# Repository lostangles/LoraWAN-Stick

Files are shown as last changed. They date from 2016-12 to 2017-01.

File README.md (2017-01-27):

# LoraWAN-Stick
PCB combining Atmega32u4, MTK3339 GPS module, and RN2903 LoraWAN module.

PCB



# Functionality
I wanted to make a single PCB that had some GPIO, communication interfaces, a module to transmit LoraWAN packets, and a way to get current location.  The LoraWAN stack is offloaded from the 32u4 and rests in a PIC microcontroller inside the RN2903.  This allows a simple interface of simply passing the payload from the 32u4 to the RN2903 without having to worry about the LoraWAN stack inside your project.

The LoraWAN-Stick incorporates the LiPo charging circuitry common to the Adafruit Feather line of dev boards, as well as follows the same pinout for attachment of Adafruit Featherwings.  Because both the RN2903 and GPS module use serial communications, serial communications with other nodes may be difficult; the GPS module uses the hardware UART, and communication to the RN2903 uses software serial.  From my experience, having multiple software serial interfaces tends to work in unexpected ways, and should probably be avoided without thorough testing.

# Pins
Pinout follows Adafruit Feather format as I wanted to be able to add compatability of Adafruit Featherwings to this project.
The 32u4 only has a single hardware UART, hard wired to the TX/RX of the GPS module.  These pins are broken out on the header.

The RN2903 is controlled by serial, but because the 32u4 has only a single UART, a software serial interface must be used.  The RN2903 is hardwired with its RX on pin 5 and TX on pin 10.  Reset for the RN2903 is hard wired to pin 6 and should be pulled high when not in reset state.  The RN2903 Pickit3 programming header is also broken out to update the firmware on the RN2903 directly.

#uC Info
The 32u4-AU microcontroller that I used here comes preconfigured to use the internal oscillator, thus the C7, C8, and XTAL pads can be left empty.  When configuring the microcontroller for the first time, it will not show up as a USB device until the bootloader has been flashed to it via ISP.  Once the bootloader has been flashed, it should show up as an Adafruit Feather 32u4 under Device Manager, and can be programmed/configured in the same manner as any of the Adafruit 32u4 Feathers.

#Radio Interface
The RN2903 by default communicates on 56000 baud.  The SoftwareSerial library is more reliable at slower speeds; to set the baudrate in the RN2903, you must send a low signal on the TX line for at least two character lengths, followed by 0x55 at the new baudrate requested.  Using the Arduino libraries, this might look like:

```
digitalWrite(10, LOW);
delay(500);
digitalWrite(10, HIGH);
rn2903.begin(9600);
rn2903.write(0x55);
```

#Fuse Settings
The bootloader included configures the 32u4 in 8 MHz in the same configuration as the Adafruit 32u4 Feathers.
The uC can be configured to run with an internal oscillator or an external oscillator.  If you use the 32u4-AU variant, the built in oscillator can be used in lieu of an external oscillator.  The fuse settings to configure the uC as such would be something like:

`avrdude -c dragon_isp -p m32u4 -U lfuse:w:0xe2:m -U hfuse:w:0xd8:m -U efuse:w:0xfb:m -U flash:w:Caterina-Feather32u4.hex -v`

# Bill Of Materials
https://github.com/lostangles/LoraWAN-Stick/blob/master/LoraWAN-Stick.xlsx

Total cost: $52.52

U3	RN2903-I/RM095	RN2903-I_RM095:XCVR_RN2903-I%2fRM095	Microchip
U2	ATmega32U4-AU	Housings_QFP:TQFP-44_10x10mm_Pitch0.8mm	
U1	FGPMMOPA6H	FGPMMOPA6H:FGPMMOPA6H	
P1	USB_OTG	Connect:USB_Mini-B	
R1	22	Resistors_SMD:R_0603_HandSoldering	
R2	22	Resistors_SMD:R_0603_HandSoldering	
U4	SPX3819	adafruit:adafruit-SOT23-5L	
R3	100k	Resistors_SMD:R_0603_HandSoldering	
C1	10uF	Capacitors_SMD:C_0603_HandSoldering	
C2	10uF	Capacitors_SMD:C_0603_HandSoldering	
C3	1uF	Capacitors_SMD:C_0603_HandSoldering	
D1	DIODESCH	Diodes_SMD:D_0805	
CN1	JST_2PIN-SMT	adafruit:adafruit-JST-PH-2-SMT	
C4	1uF	Capacitors_SMD:C_0603_HandSoldering	
SW1	SPST	open-project:SW_PUSH_SMD	
U5	MCP73831	arthurc:SOT23-5	
D2	LED-BAT	Diodes_SMD:D_0805	
R4	1k	Resistors_SMD:R_0603_HandSoldering	
R5	10k	Resistors_SMD:R_0603_HandSoldering	
C5	10uF	Capacitors_SMD:C_0603_HandSoldering	
R6	100k	Resistors_SMD:R_0603_HandSoldering	
R7	100k	Resistors_SMD:R_0603_HandSoldering	
C6	10uF	Capacitors_SMD:C_0603_HandSoldering	
JP3	PINHD-1X12	adafruit:adafruit-1X12	
JP1	CONN_01X16	Pin_Headers:Pin_Header_Straight_1x16	
JP2	PINHD-1X6	adafruit:adafruit-1X06	
ANT1	CON-SMA	misc:CON-SMA-EDGE	
D3	LED-RED	Diodes_SMD:D_0805	
R8	1k	Resistors_SMD:R_0603_HandSoldering	
D4	LED-POW	Diodes_SMD:D_0805	
R9	1k	Resistors_SMD:R_0603_HandSoldering	

# TODO 

Add ICP header for 32u4

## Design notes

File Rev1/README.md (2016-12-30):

# LoraWAN-Stick
PCB combining Atmega32u4, MTK3339 GPS module, and RN2903 LoraWAN module
This is rev 0; changes will probably need to be made once I get PCBs in and test them

OSHPark permalink: 
https://oshpark.com/shared_projects/INShZUhB

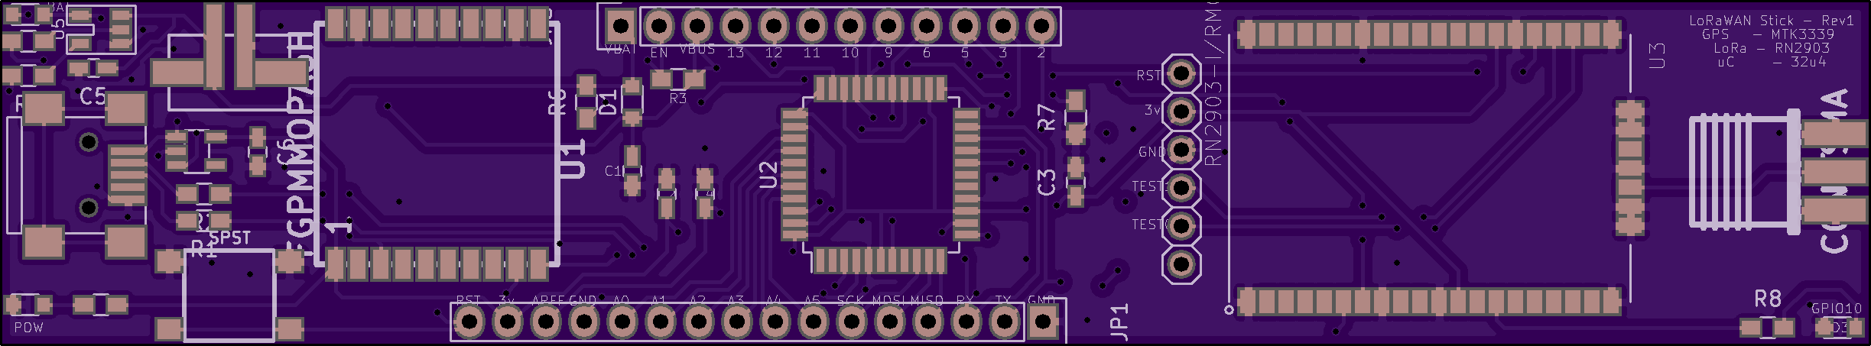
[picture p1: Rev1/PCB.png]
PCB


# Functionality
I wanted to make a single PCB that had some GPIO, communication interfaces, a module to transmit LoraWAN packets, and a way to get current location.  The LoraWAN stack is offloaded from the 32u4 and rests in a PIC microcontroller inside the RN2903.  This allows a simple interface of simply passing the payload from the 32u4 to the RN2903 without having to worry about the LoraWAN stack inside your project.

The LoraWAN-Stick incorporates the LiPo charging circuitry common to the Adafruit Feather line of dev boards, as well as follows the same pinout for attachment of Adafruit Featherwings.  Because both the RN2903 and GPS module use serial communications, serial communications with other nodes may be difficult; the GPS module uses the hardware UART, and communication to the RN2903 uses software serial.  From my experience, having multiple software serial interfaces tends to work in unexpected ways, and should probably be avoided without thorough testing.

# Pins
Pinout follows Adafruit Feather format as I wanted to be able to add compatability of Adafruit Featherwings to this project.
The 32u4 only has a single hardware UART, hard wired to the TX/RX of the GPS module.  These pins are broken out on the header.

The RN2903 is controlled by serial, but because the 32u4 has only a single UART, a software serial interface must be used.  The RN2903 is hardwired with its RX on pin 5 and TX on pin 10.  Reset for the RN2903 is hard wired to pin 6 and should be pulled high when not in reset state.  The RN2903 Pickit3 programming header is also broken out to update the firmware on the RN2903 directly.

# Bill Of Materials
https://github.com/lostangles/LoraWAN-Stick/blob/master/LoraWAN-Stick.xlsx

Total cost: $52.52

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

# TODO 

Verify all functionality

Verify pin header compatbility

Add ICP for 32u4

Verify software serial pins work correctly

Add mounting holes on corners

Add external oscillator

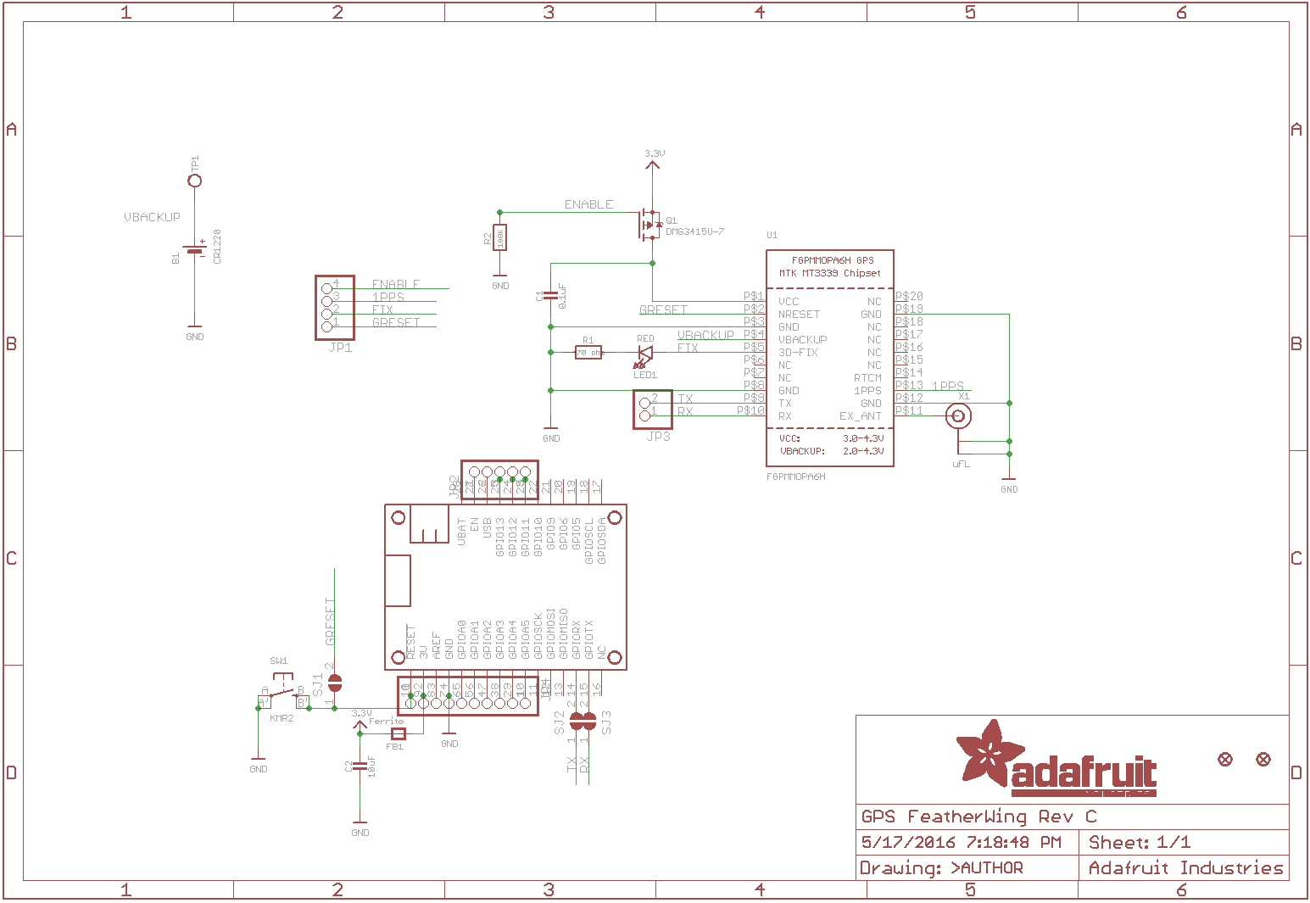
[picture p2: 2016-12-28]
Rev1/datasheets/gps_schem.png

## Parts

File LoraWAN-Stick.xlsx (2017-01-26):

Reference | Value | Footprint | Price | Link
U3 | RN2903-I/RM095 | RN2903-I_RM095:XCVR_RN2903-I%2fRM095 | 14.7 | http://www.digikey.com/products/en?mpart=RN2903-I%2FRM095&v=150
U2 | ATmega32U4-AU | Housings_QFP:TQFP-44_10x10mm_Pitch0.8mm | 6.32 | http://www.digikey.com/product-detail/en/atmel/ATMEGA32U4RC-AU/ATMEGA32U4RC-AU-ND/2507982
U1 | FGPMMOPA6H | FGPMMOPA6H:FGPMMOPA6H | 11.8 | https://www.aliexpress.com/item/FGPMMOPA6H-utilizes-the-MediaTek-new-generation-GPS-Chipset-MT3339/623742154.html
P1 | USB_OTG | Connect:USB_Mini-B | 0.6 | http://www.digikey.com/product-detail/en/edac-inc/690-005-299-043/151-1206-1-ND/4312192
R1 | 22 | Resistors_SMD:R_0603_HandSoldering | 0.1 | http://www.digikey.com/product-detail/en/yageo/RC0603JR-0722RL/311-22GRCT-ND/729690
R2 | 22 | Resistors_SMD:R_0603_HandSoldering | 0.1 | http://www.digikey.com/product-detail/en/yageo/RC0603JR-0722RL/311-22GRCT-ND/729690
U4 | SPX3819 | adafruit:adafruit-SOT23-5L | 0.72 | http://www.digikey.com/product-detail/en/exar-corporation/SPX3819M5-L-3-3-TR/1016-1873-1-ND/3586590
R3 | 100k | Resistors_SMD:R_0603_HandSoldering | 0.1 | http://www.digikey.com/product-detail/en/yageo/RC0603JR-07100KL/311-100KGRCT-ND/729645
C1 | 10uF | Capacitors_SMD:C_0603_HandSoldering | 0.15 | http://www.digikey.com/product-detail/en/murata-electronics-north-america/GRM188R60J106ME47D/490-3896-1-ND/965938
C2 | 10uF | Capacitors_SMD:C_0603_HandSoldering | 0.15 | http://www.digikey.com/product-detail/en/murata-electronics-north-america/GRM188R60J106ME47D/490-3896-1-ND/965938
C3 | 1uF | Capacitors_SMD:C_0603_HandSoldering | 0.1 | http://www.digikey.com/product-detail/en/murata-electronics-north-america/GRM188R61C105KA93D/490-1536-1-ND/587769
D1 | DIODESCH | Diodes_SMD:D_0805 | 0.47 | http://www.digikey.com/product-detail/en/on-semiconductor/MBR120VLSFT1G/MBR120VLSFT1GOSCT-ND/893874
CN1 | JST_2PIN-SMT | adafruit:adafruit-JST-PH-2-SMT | 0.55 | http://www.digikey.com/product-detail/en/jst-sales-america-inc/B2B-PH-SM4-TB(LF)(SN)/455-1734-1-ND/926831
C4 | 1uF | Capacitors_SMD:C_0603_HandSoldering | 0.1 | http://www.digikey.com/product-detail/en/murata-electronics-north-america/GRM188R61C105KA93D/490-1536-1-ND/587769
SW1 | SPST | open-project:SW_PUSH_SMD | 2.43 | http://www.digikey.com/product-detail/en/rafi-usa/1.14100.5030000/1715-1676-1-ND/583462
U5 | MCP73831 | arthurc:SOT23-5 | 0.58 | http://www.digikey.com/product-detail/en/microchip-technology/MCP73831T-2DCI-OT/MCP73831T-2DCI-OTCT-ND/1979804
D2 | LED-BAT | Diodes_SMD:D_0805 | 0.26 | http://www.digikey.com/product-detail/en/osram-opto-semiconductors-inc/LH-R974-LP-1/475-1415-1-ND/1802604
R4 | 1k | Resistors_SMD:R_0603_HandSoldering | 0.1 | http://www.digikey.com/product-detail/en/yageo/RC0603JR-071KL/311-1.0KGRCT-ND/729624
R5 | 10k | Resistors_SMD:R_0603_HandSoldering | 0.1 | http://www.digikey.com/product-detail/en/yageo/RC0603JR-0710KL/311-10KGRCT-ND/729647
C5 | 10uF | Capacitors_SMD:C_0603_HandSoldering | 0.15 | http://www.digikey.com/product-detail/en/murata-electronics-north-america/GRM188R60J106ME47D/490-3896-1-ND/965938
R6 | 100k | Resistors_SMD:R_0603_HandSoldering | 0.1 | http://www.digikey.com/product-detail/en/yageo/RC0603JR-07100KL/311-100KGRCT-ND/729645
R7 | 100k | Resistors_SMD:R_0603_HandSoldering | 0.1 | http://www.digikey.com/product-detail/en/yageo/RC0603JR-07100KL/311-100KGRCT-ND/729645
C6 | 10uF | Capacitors_SMD:C_0603_HandSoldering | 0.15 | http://www.digikey.com/product-detail/en/murata-electronics-north-america/GRM188R60J106ME47D/490-3896-1-ND/965938
JP3 | PINHD-1X12 | adafruit:adafruit-1X12 | 0.73 | http://www.digikey.com/product-detail/en/3m/951112-8622-AR/3M9330-ND/1959058
JP1 | CONN_01X16 | Pin_Headers:Pin_Header_Straight_1x16 | 0.76 | http://www.digikey.com/product-detail/en/amphenol-fci/68002-116HLF/609-3295-ND/1878570
JP2 | PINHD-1X6 | adafruit:adafruit-1X06
ANT1 | CON-SMA | misc:CON-SMA-EDGE | 2.98 | http://www.digikey.com/product-detail/en/taoglas-limited/EMPCB.SMAFSTJ.C.HT/931-1174-ND/3522338
D3 | LED-RED | Diodes_SMD:D_0805 | 0.26
R8 | 1k | Resistors_SMD:R_0603_HandSoldering | 0.1 | http://www.digikey.com/product-detail/en/yageo/RC0603JR-071KL/311-1.0KGRCT-ND/729624
D4 | LED-POW | Diodes_SMD:D_0805 | 0.26
R9 | 1k | Resistors_SMD:R_0603_HandSoldering | 0.1 | http://www.digikey.com/product-detail/en/yageo/RC0603JR-071KL/311-1.0KGRCT-ND/729624
PCB |  |  | 7.4
 |  |  | 52.52

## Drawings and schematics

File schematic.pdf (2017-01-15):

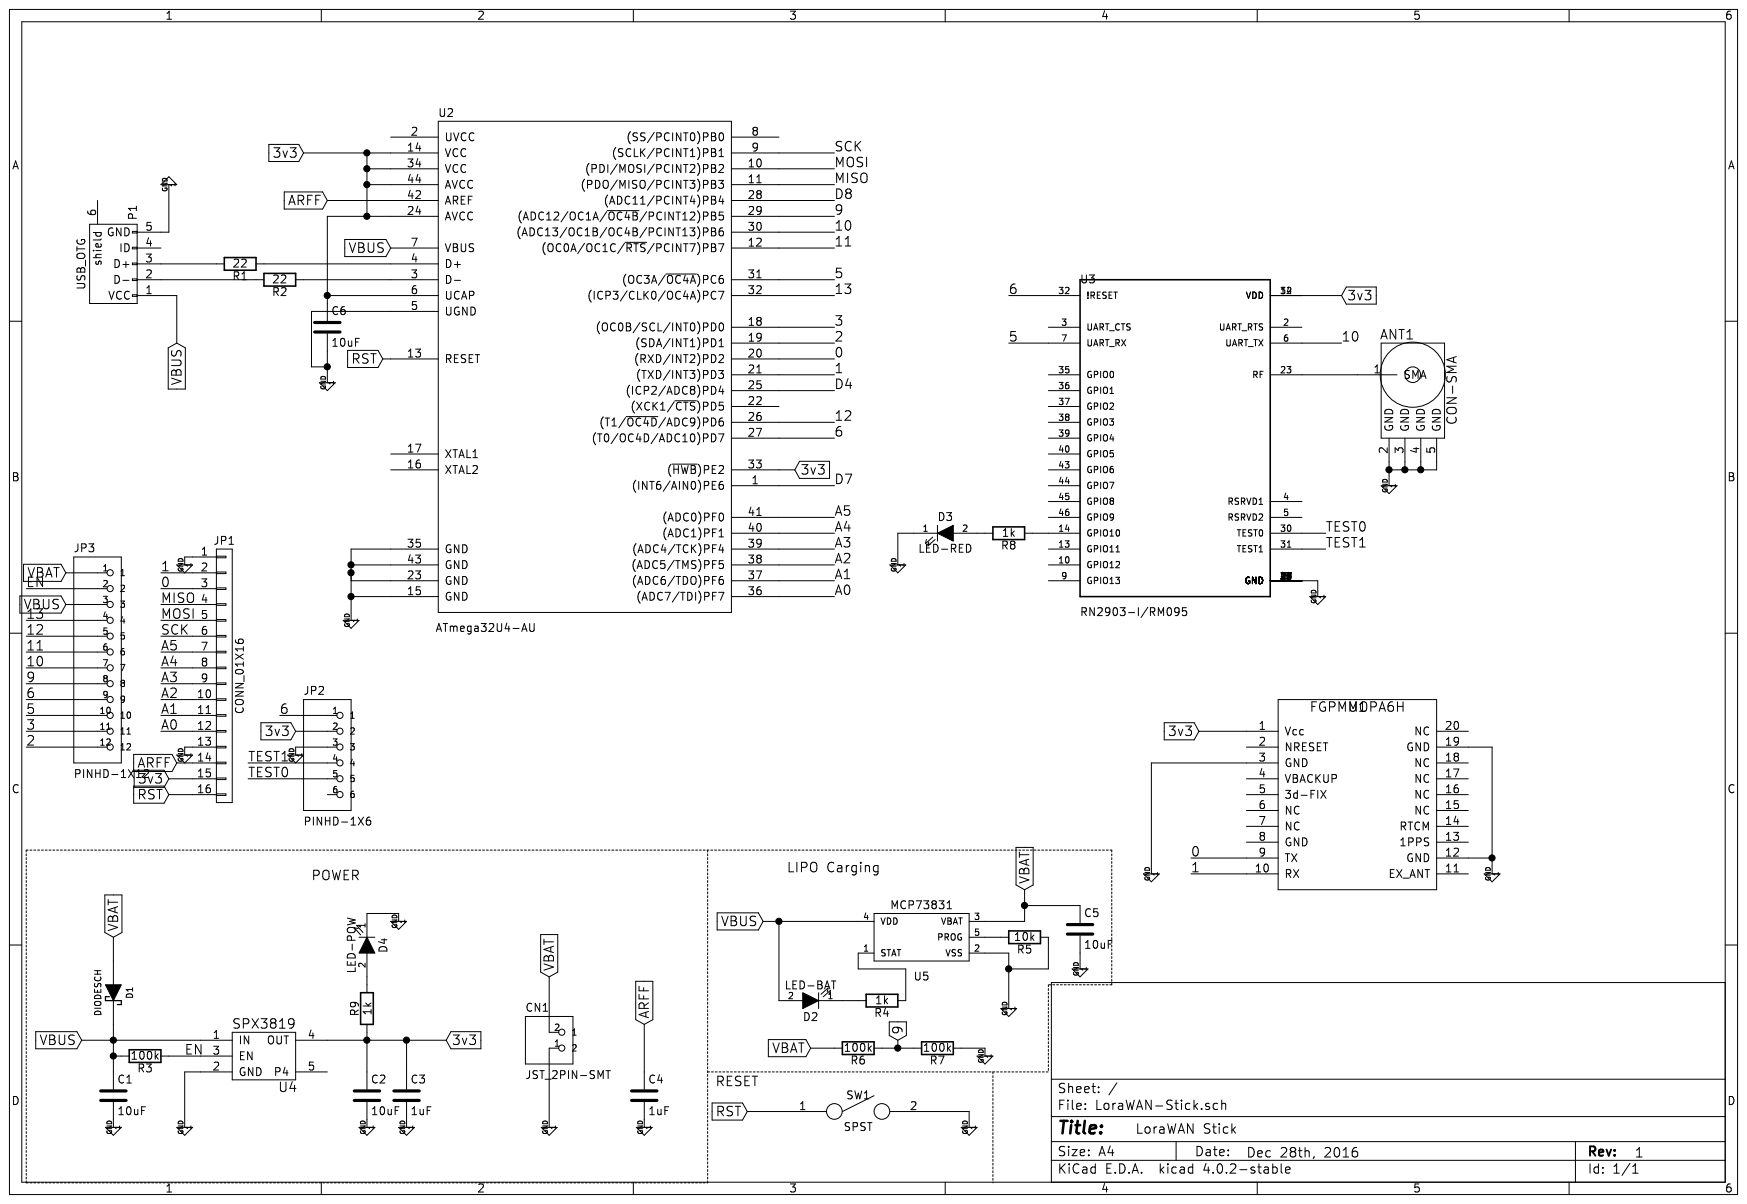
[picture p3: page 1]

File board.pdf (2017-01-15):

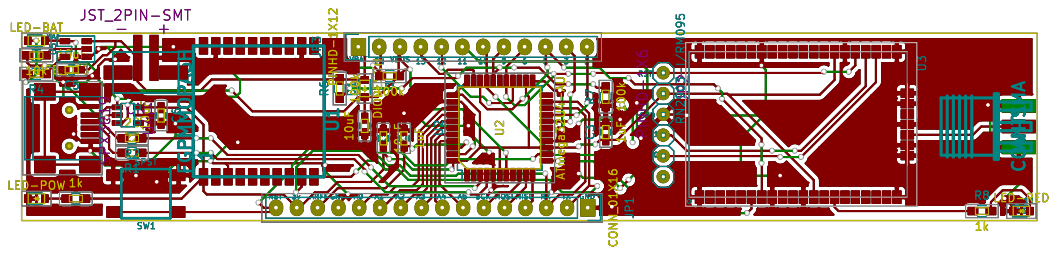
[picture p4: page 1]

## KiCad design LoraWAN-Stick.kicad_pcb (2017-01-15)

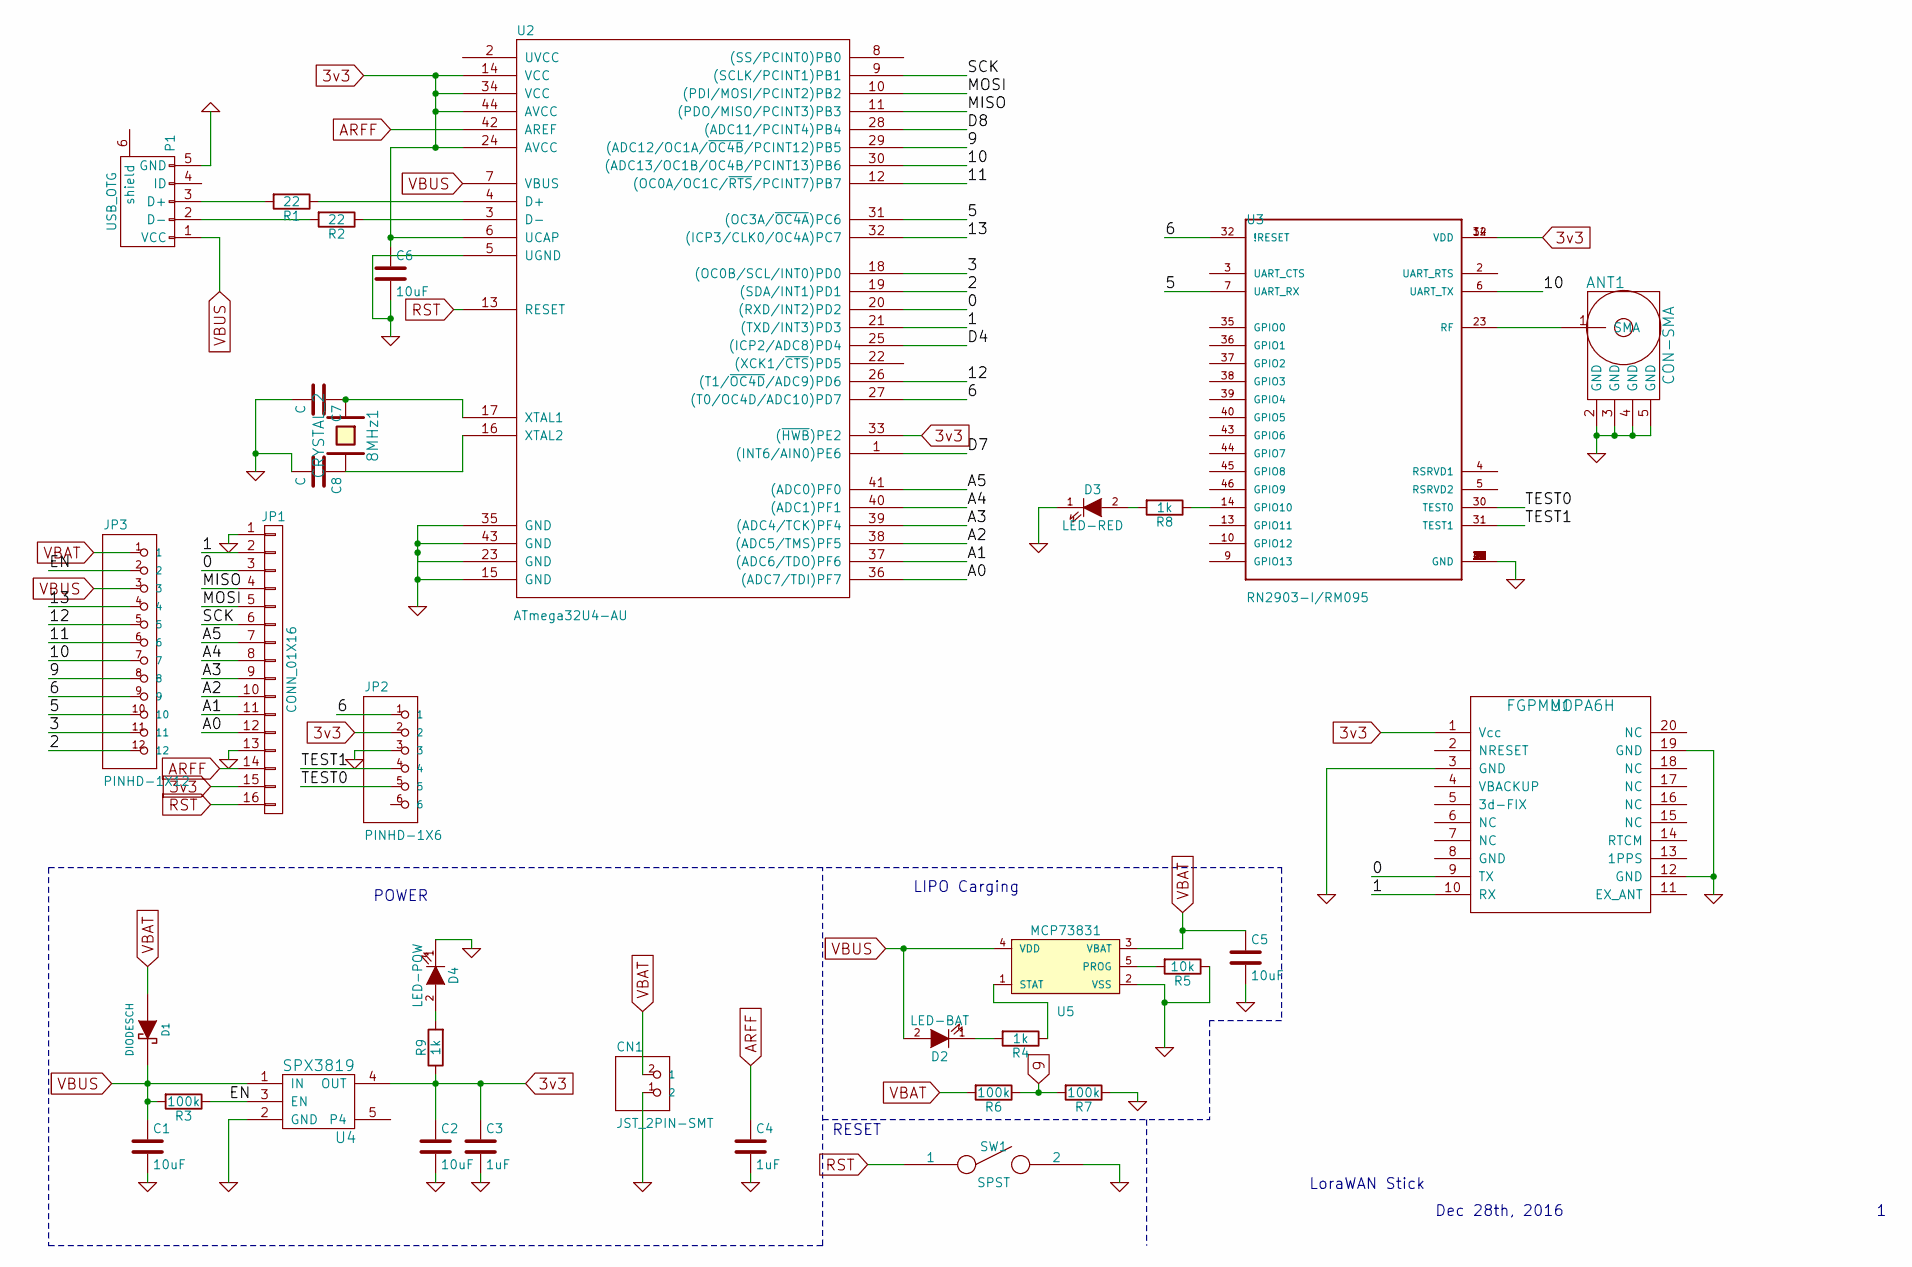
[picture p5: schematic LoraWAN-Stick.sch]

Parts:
8MHz1: CRYSTAL_2; ABM3
ANT1: CON-SMA; CON-SMA-EDGE
C1, C2, C5, C6: 10uF; C_0603_HandSoldering
C3, C4: 1uF; C_0603_HandSoldering
C7, C8: C; C_0603_HandSoldering
CN1: JST_2PIN-SMT; adafruit-JST-PH-2-SMT
D1: DIODESCH; D_0805
D2: LED-BAT; D_0805
D3: LED-RED; D_0805
D4: LED-POW; D_0805
JP1: CONN_01X16; Pin_Header_Straight_1x16
JP2: PINHD-1X6; adafruit-1X06
JP3: PINHD-1X12; adafruit-1X12
P1: USB_OTG; USB_Mini-B
R1, R2: 22; R_0603_HandSoldering
R3, R6, R7: 100k; R_0603_HandSoldering
R4, R8, R9: 1k; R_0603_HandSoldering
R5: 10k; R_0603_HandSoldering
SW1: SPST; SW_PUSH_SMD
U1: FGPMMOPA6H
U2: ATmega32U4-AU; TQFP-44_10x10mm_Pitch0.8mm
U3: RN2903-I/RM095; XCVR_RN2903-I%2fRM095
U4: SPX3819; adafruit-SOT23-5L
U5: MCP73831; SOT23-5

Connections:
3v3: C2.1, C3.1, C6.1, JP1.15, JP2.2, R9.1, U1.1 (Vcc), U2.6 (UCAP), U2.14 (VCC), U2.24 (AVCC), U2.33 ((~HWB~)PE2), U2.34 (VCC), U2.44 (AVCC), U3.12 (VDD), U3.34 (VDD), U4.4 (OUT)
9: JP3.8, R6.1, R7.2, U2.29 ((ADC12/OC1A/~OC4B~/PCINT12)PB5)
/0: JP1.3, U1.9 (TX), U2.20 ((RXD/INT2)PD2)
/1: JP1.2, U1.10 (RX), U2.21 ((TXD/INT3)PD3)
/2: JP3.12, U2.19 ((SDA/INT1)PD1)
/3: JP3.11, U2.18 ((OC0B/SCL/INT0)PD0)
/5: JP3.10, U2.31 ((OC3A/~OC4A~)PC6), U3.7 (UART_RX)
/6: JP2.1, JP3.9, U2.27 ((T0/OC4D/ADC10)PD7), U3.32 (!RESET)
/10: JP3.7, U2.30 ((ADC13/OC1B/OC4B/PCINT13)PB6), U3.6 (UART_TX)
/11: JP3.6, U2.12 ((OC0A/OC1C/~RTS~/PCINT7)PB7)
/12: JP3.5, U2.26 ((T1/~OC4D~/ADC9)PD6)
/13: JP3.4, U2.32 ((ICP3/CLK0/OC4A)PC7)
/A0: JP1.12, U2.36 ((ADC7/TDI)PF7)
/A1: JP1.11, U2.37 ((ADC6/TDO)PF6)
/A2: JP1.10, U2.38 ((ADC5/TMS)PF5)
/A3: JP1.9, U2.39 ((ADC4/TCK)PF4)
/A4: JP1.8, U2.40 ((ADC1)PF1)
/A5: JP1.7, U2.41 ((ADC0)PF0)
/D4: U2.25 ((ICP2/ADC8)PD4)
/D7: U2.1 ((INT6/AIN0)PE6)
/D8: U2.28 ((ADC11/PCINT4)PB4)
/EN: JP3.2, R3.1, U4.3 (EN)
/MISO: JP1.4, U2.11 ((PDO/MISO/PCINT3)PB3)
/MOSI: JP1.5, U2.10 ((PDI/MOSI/PCINT2)PB2)
/SCK: JP1.6, U2.9 ((SCLK/PCINT1)PB1)
/TEST0: JP2.5, U3.30 (TEST0)
/TEST1: JP2.4, U3.31 (TEST1)
ARFF: C4.1, JP1.14, U2.42 (AREF)
GND: ANT1.2 (GND), ANT1.3 (GND), ANT1.4 (GND), ANT1.5 (GND), C1.2, C2.2, C3.2, C4.2, C5.2, C6.2, C7.2, C8.2, CN1.1 (2), D3.1 (K), D4.1 (K), JP1.1, JP1.13, JP2.3, P1.5 (GND), R5.1, R7.1, SW1.2, U1.3 (GND), U1.12 (GND), U1.19 (GND), U2.5 (UGND), U2.15 (GND), U2.23 (GND), U2.35 (GND), U2.43 (GND), U3.1 (GND), U3.8 (GND), U3.11 (GND), U3.20 (GND), U3.21 (GND), U3.22 (GND), U3.24 (GND), U3.26 (GND), U3.27 (GND), U3.28 (GND), U3.33 (GND), U3.41 (GND), U3.47 (GND), U4.2 (GND), U5.2 (VSS)
unnamed: 8MHz1.1, C7.1, U2.17 (XTAL1)
unnamed: 8MHz1.2, C8.1, U2.16 (XTAL2)
unnamed: ANT1.1 (SMA), U3.23 (RF)
unnamed: D2.1 (K), R4.2
unnamed: D3.2 (A), R8.2
unnamed: D4.2 (A), R9.2
unnamed: P1.2 (D-), R2.2
unnamed: P1.3 (D+), R1.2
unnamed: R1.1, U2.4 (D+)
unnamed: R2.1, U2.3 (D-)
unnamed: R4.1, U5.1 (STAT)
unnamed: R5.2, U5.5 (PROG)
unnamed: R8.1, U3.14 (GPIO10)
RST: JP1.16, SW1.1, U2.13 (RESET)
VBAT: C5.1, CN1.2 (1), D1.1 (A), JP3.1, R6.2, U5.3 (VBAT)
VBUS: C1.1, D1.2 (K), D2.2 (A), JP3.3, P1.1 (VCC), R3.2, U2.7 (VBUS), U4.1 (IN), U5.4 (VDD)

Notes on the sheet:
POWER
RESET
LIPO Carging
LoraWAN Stick
Dec 28th, 2016

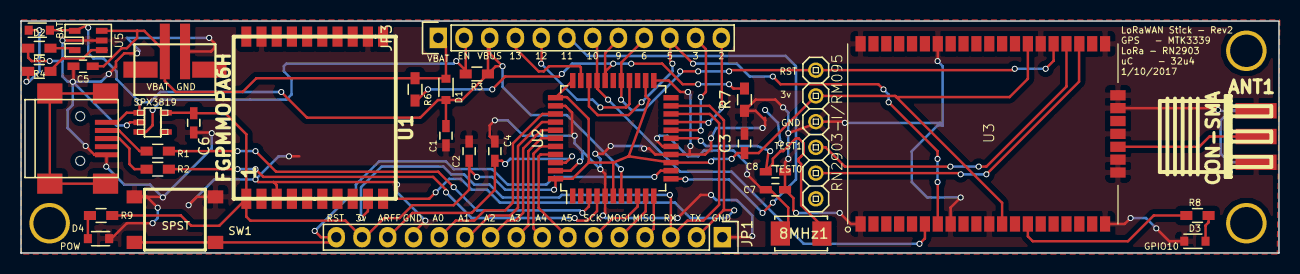
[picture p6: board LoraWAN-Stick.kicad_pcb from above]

Board: 2 copper layers, 124.1 x 22.9 mm, 34 parts (0 on the bottom side), 42 nets.

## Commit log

2016-12-28 Initial commit
    Initial commit
    [LoraWAN-Stick.csv, LoraWAN-Stick.kicad_pcb, LoraWAN-Stick.sch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]
2016-12-29 Updated BOM with price + links
    [LoraWAN-Stick.csv, LoraWAN-Stick.xlsx]
2017-01-15 Fixed LiPo charging, added holes on edges, added pads for external crystal, cleaned up silk screen
    [LoraWAN-Stick.csv, LoraWAN-Stick.kicad_pcb, LoraWAN-Stick.sch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]
2017-01-15 Rev2
    Fixed LiPo charging, added holes on edges, added pads for external
    crystal, cleaned up silk screen
2017-01-15 Fixed PCB image
2017-01-26 Added bootloader
    [LoraWAN-Stick.xlsx]
